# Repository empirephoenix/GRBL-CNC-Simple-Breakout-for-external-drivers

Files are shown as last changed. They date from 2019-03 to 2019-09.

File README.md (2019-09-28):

# GRBL-CNC-Simple-Breakout-for-external-drivers
I wanted a simple CNC produceable breakout board, to use as a shield on, that is sufficient to be used for external motor drivers

Basically the CNC I'm running is a bit larger than the usual stock GRBL builds.

-> This means it runs with an external Brushless spindle controller, that requires the PWM signal

-> This also means that no Polulu like stepper drivers are used, instead they are external as well.

-> Last but not least, this means that space is premium in my controller box, so this shield was designed to not require more space than necessary

Additionally:

-> To allow fast building, this shield can be created with a one sided PCB, allowing it to be created with even the cheapest CNC kits

-> The amount of bridge wires is reduced as much as I'm capable of

-> Everything can either be plugged using JST (recommended) pin headers, or directly solderd onto the board

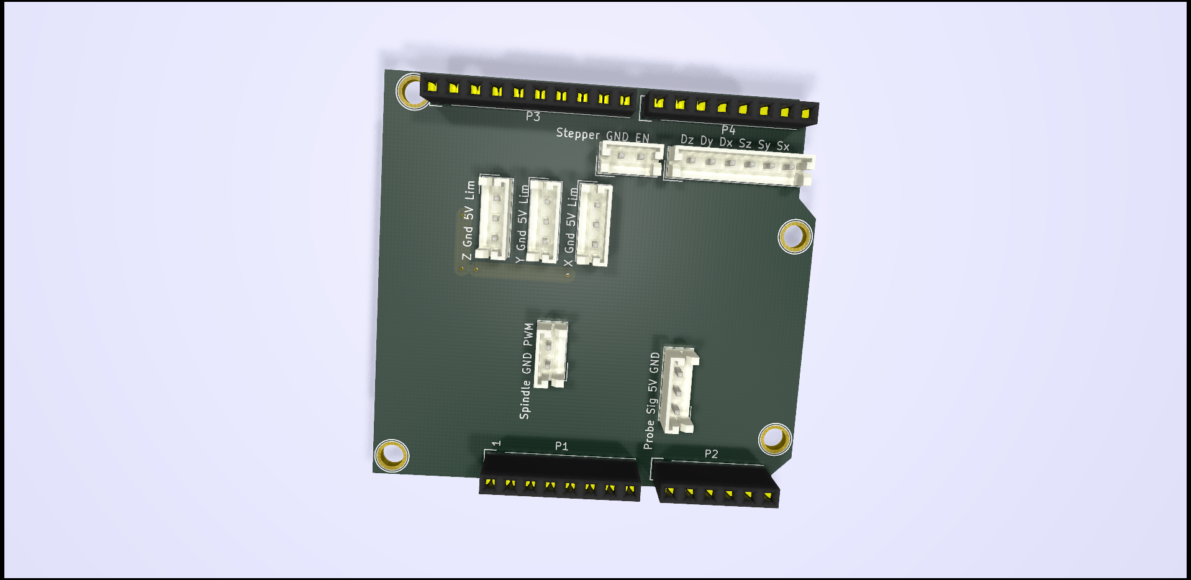
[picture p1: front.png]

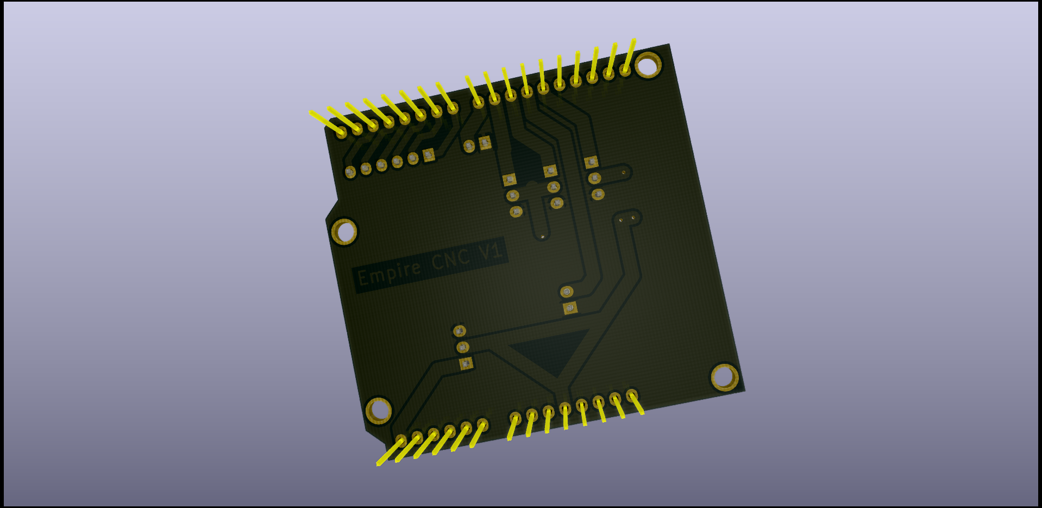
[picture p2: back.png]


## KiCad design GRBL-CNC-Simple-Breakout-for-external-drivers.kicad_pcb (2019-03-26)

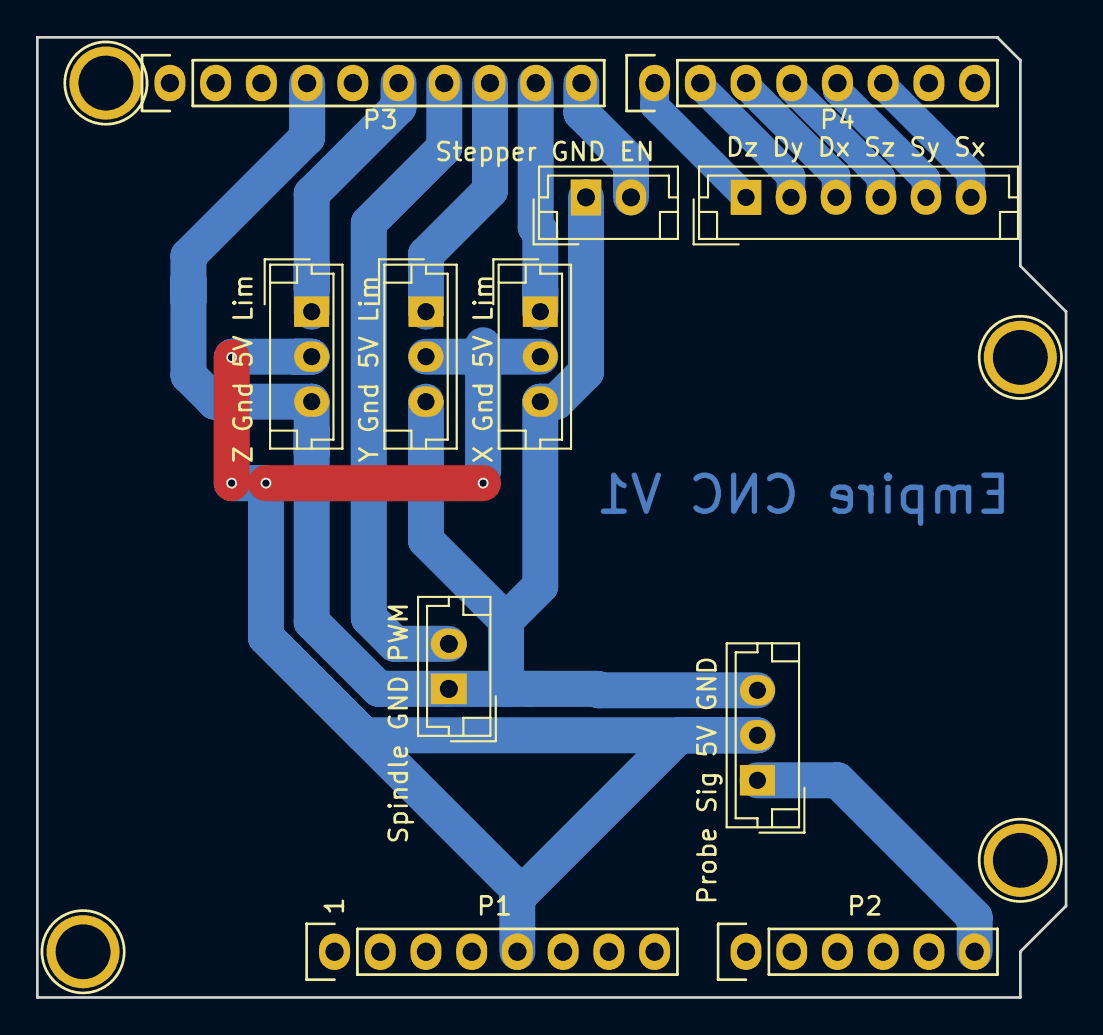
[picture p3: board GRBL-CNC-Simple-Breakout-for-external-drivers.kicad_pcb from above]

Board: 2 copper layers, 57.2 x 53.3 mm, 15 parts (0 on the bottom side), 14 nets.

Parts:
Dz Dy Dx Sz Sy Sx: Steppers; JST_EH_B06B-EH-A_1x06_P2.50mm_Vertical
P1: Power; Socket_Strip_Arduino_1x08
P2: Analog; Socket_Strip_Arduino_1x06
P3: Digital; Socket_Strip_Arduino_1x10
P4: Digital; Socket_Strip_Arduino_1x08
P5, P6, P7, P8: CONN_01X01; Arduino_1pin
Probe Sig 5V GND: Probe; JST_EH_B03B-EH-A_1x03_P2.50mm_Vertical
Spindle GND PWM: spindle; JST_EH_B02B-EH-A_1x02_P2.50mm_Vertical
Stepper GND EN: JST_EH_B02B-EH-A_1x02_P2.50mm_Vertical
X Gnd 5V Lim: LimitX; JST_EH_B03B-EH-A_1x03_P2.50mm_Vertical
Y Gnd 5V Lim: LimitY; JST_EH_B03B-EH-A_1x03_P2.50mm_Vertical
Z Gnd 5V Lim: LimitZ; JST_EH_B03B-EH-A_1x03_P2.50mm_Vertical

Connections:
5V: P1.5, Probe Sig 5V GND.2, X Gnd 5V Lim.2, Y Gnd 5V Lim.2, Z Gnd 5V Lim.2
DirX: Dz Dy Dx Sz Sy Sx.3, P4.3
DirY: Dz Dy Dx Sz Sy Sx.2, P4.2
DirZ: Dz Dy Dx Sz Sy Sx.1, P4.1
GND-USB: P3.4, Probe Sig 5V GND.3, Spindle GND PWM.1, Stepper GND EN.1, X Gnd 5V Lim.3, Y Gnd 5V Lim.3, Z Gnd 5V Lim.3
LimitX: P3.9, X Gnd 5V Lim.1
LimitY: P3.8, Y Gnd 5V Lim.1
LimitZ: P3.6, Z Gnd 5V Lim.1
Probe: P2.6, Probe Sig 5V GND.1
SpindlePWM: P3.7, Spindle GND PWM.2
StepX: Dz Dy Dx Sz Sy Sx.6, P4.6
StepY: Dz Dy Dx Sz Sy Sx.5, P4.5
StepZ: Dz Dy Dx Sz Sy Sx.4, P4.4
StepperEN: P3.10, Stepper GND EN.2

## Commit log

2019-03-25 V1 design
    [GRBL-CNC-Simple-Breakout-for-external-drivers.kicad_pcb, GRBL-CNC-Simple-Breakout-for-external-drivers.sch]
2019-03-26 increased traces width, to produce it without any z homing capability (aka allow breadboard controller with minimal wireing to produce this)
    [GRBL-CNC-Simple-Breakout-for-external-drivers.kicad_pcb]
